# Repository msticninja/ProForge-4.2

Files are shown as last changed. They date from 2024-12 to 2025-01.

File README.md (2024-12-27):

# ProForge 4.2 Tool Changer 3D Printer

P4 2 Enclosure Render

Designed in the UK, the ProForge 4.2 Tool Changer is a state-of-the-art multi-tool 3D printer designed for precision, reliability, and modularity. With its advanced tool-changing mechanism, it enables seamless multi-material and multi-function printing for hobbyists, engineers, and makers.

Available to order [here.](https://www.makertech3d.com/pages/proforge-4)

# Features
	•	Tool-Changing Mechanism: Swap up to 4 tools in a single print.
	•	Large Build Volume: 300mm x 400mm x 400mm.
	•	Multi-Material Compatibility: Support for various filaments like PLA, ABS, PETG, and flexible materials.
	•	Advanced Calibration System: Automated nozzle alignment and offset calibration.
	•	Bed Scanning: A mesh of 2500 points is created in seconds for the perfect first layer.
	•	Klipper Firmware: High-speed and responsive motion control.

# ProForge 4.2 Klipper Firmware Image

The Klipper firmware image is available to download [here](https://mega.nz/file/s3c2yLpL#45p-zCgpL2xGsliyOl72hiXyFS9ZQuSpQ91LdNRgVnc).

# ProForge 4.2 Build Manual

The Official build guides for the ProForge 4.2 3D printer can be found [here](https://makertech-3d.dozuki.com/c/ProForge_4.2)

# Support and Community

If you run into any issues or need assistance with assembly or printing, feel free to ask for help in the official [Discord Server](https://discord.com/invite/FwgXFUw4R4)  or [Facebook Group](https://www.facebook.com/groups/proforge4).

If you’re missing a part or have received a faulty/broken one, please fill out [this form](https://www.makertech3d.com/missingpartform) for a replacement.

Want to get in touch? Drop us an email at info@makertech3d.com

# Safety Notice

Operate the ProForge 4.2 in a well ventilated, open and dry environment.

Be aware of the moving parts, there is a pinching hazard.

Be cautious of the Hotend, it can reach temperatures exceeding 300 degrees Celsius, this is hot enough to cause severe burns. Even after operation, the hotends can still be hot, allow time for them to cool before touching.

Keep children and pets away from the ProForge 4.2 whilst in operation.

Never disconnect any of the wiring whilst powered on.

Be careful of long hair and loose clothing when operating the ProForge 4.2.

Immediately shut down the ProForge 4.2 if an error occurs to prevent damage to the unit or its surroundings.

# Disclaimer

THIS PRODUCT IS A DO-IT-YOURSELF KIT TO BE ASSEMBLED BY THE USER AT THEIR OWN RISK. MAKERTECH 3D LTD DISCLAIMS ALL RESPONSIBILITY, RISK, OR LIABILITY OF ANY DAMAGE OR INJURY TO YOURSELF OR ANY PERSON OR PROPERTY FROM ITS USE.

NEITHER MAKERTECH 3D NOR ITS SUPPLIERS SHALL BE LIABLE TO YOU OR TO ANY THIRD PARTY FOR ANY INDIRECT, INCIDENTAL, CONSEQUENTIAL, SPECIAL, PUNITIVE, OR EXEMPLARY DAMAGES (INCLUDING IN EACH CASE, BUT NOT LIMITED TO, DAMAGES FOR THE INABILITY TO USE OR ACCESS THE PRODUCTS, LOSS OF DATA, LOSS OF BUSINESS, LOSS OF PROFITS, BUSINESS INTERRUPTION OR THE LIKE) ARISING OUT OF THE USE OF OR INABILITY TO USE THE PRODUCTS, EVEN IF MAKERTECH 3D HAS BEEN ADVISED OF THE POSSIBILITY OF SUCH DAMAGES.

MAKERTECH 3D IS NOT RESPONSIBLE FOR ANY PRODUCTS (3D PRINTED PARTS OR OTHER) PRODUCED WITH THE PROFORGE 3 OR ANY OF ITS OTHER PRODUCTS. IN NO EVENT SHALL MAKERTECH 3D BE LIABLE FOR ANY DAMAGE OR INJURY OCCURRED BY USING PRODUCTS PRODUCED BY THE PROFORGE 3 OR ANY OF ITS OTHER PRODUCTS.

NOTWITHSTANDING ANY DAMAGES THAT YOU MIGHT INCUR FOR ANY REASON WHATSOEVER (INCLUDING, WITHOUT LIMITATION, ALL DAMAGES REFERENCED HEREIN AND ALL DIRECT OR GENERAL DAMAGES IN CONTRACT OR ANYTHING ELSE), THE ENTIRE LIABILITY OF MAKERTECH 3D AND ANY OF ITS SUPPLIERS ARISING FROM OR RELATED TO THE USE OF THE PRODUCTS SHALL BE LIMITED TO THE AMOUNT ACTUALLY PAID BY YOU FOR THE PRODUCTS CONCERNED.

THE CUSTOMER IS FULLY AWARE OF THE TERMS OF USE MENTIONED IN THE ASSEMBLY MANUALS PROVIDED WITH THE PRODUCT AND AGREES WITH THESE TERMS OF USE WHEN ACCEPTING THE PRODUCT.

THE CUSTOMER HAS READ THE SAFETY INSTRUCTIONS PROVIDED IN THE MANUALS TO BUILD THE DIY-PRODUCTS OF MAKERTECH 3D. THE CUSTOMER ALSO AGREES IN FOLLOWING THESE SAFETY INSTRUCTIONS.

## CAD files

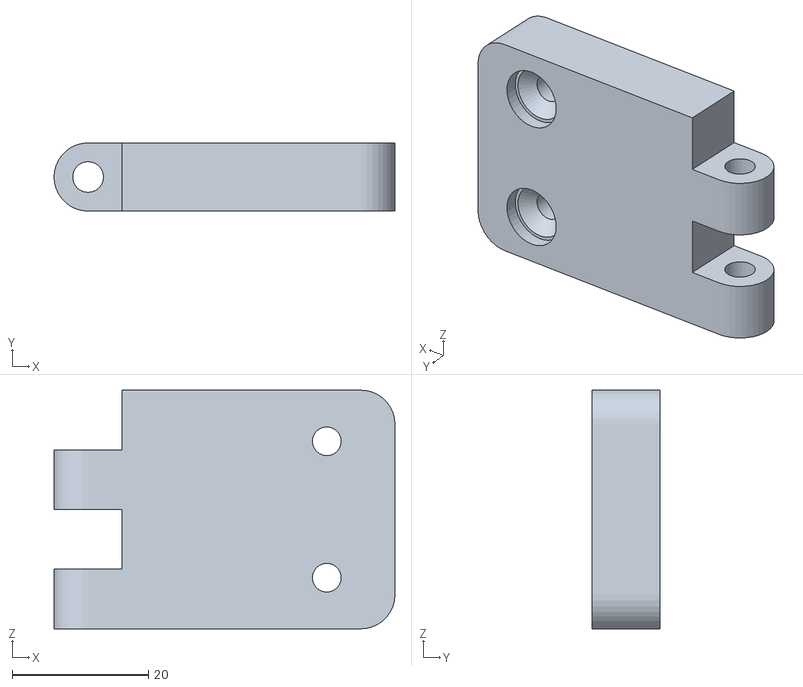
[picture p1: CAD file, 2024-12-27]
3D Printed Parts/P4.2 - Roof Hinge A.STL
50.0 x 10.0 x 35.0

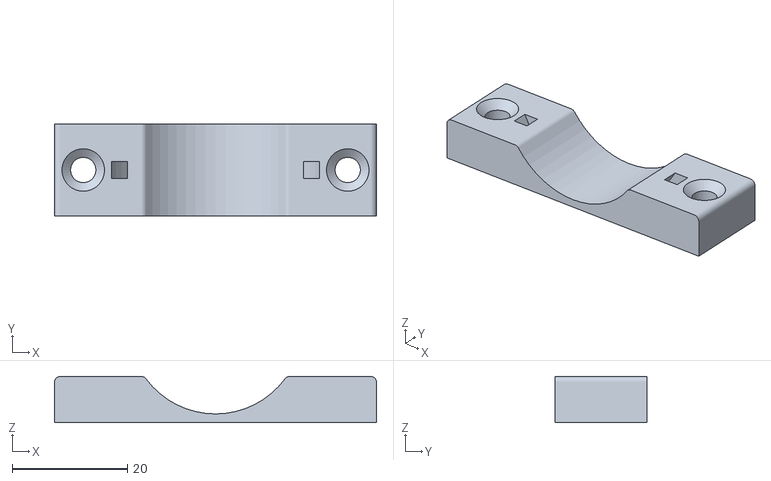
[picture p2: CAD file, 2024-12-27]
3D Printed Parts/P4.2 - CPAP Support Bracket.STL
56.0 x 16.0 x 8.02

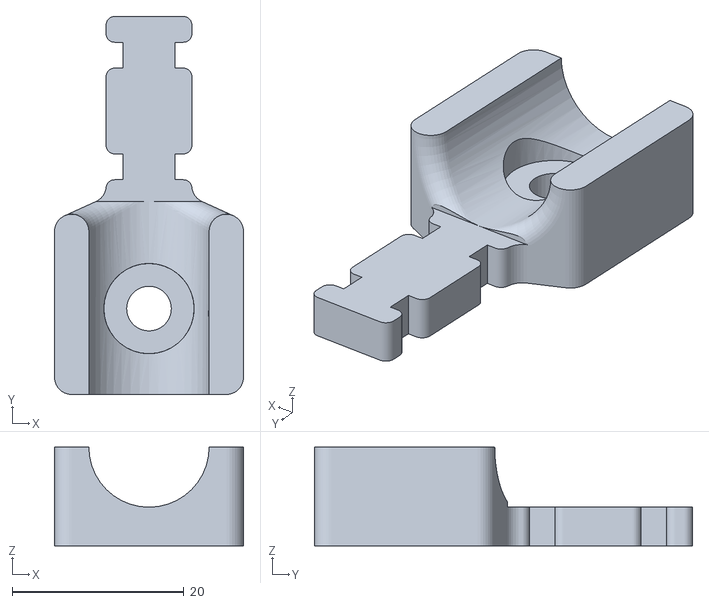
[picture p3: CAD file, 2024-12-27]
3D Printed Parts/P4.2 - Cable Relief.STL
22.0 x 44.0 x 11.5

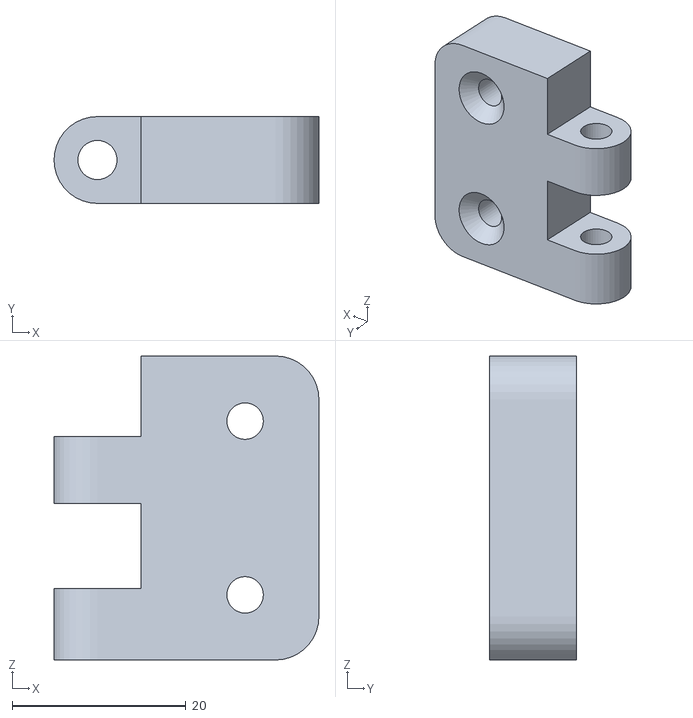
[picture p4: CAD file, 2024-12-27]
3D Printed Parts/P4.2 - Roof Hinge B.STL
30.5 x 10.0 x 35.0

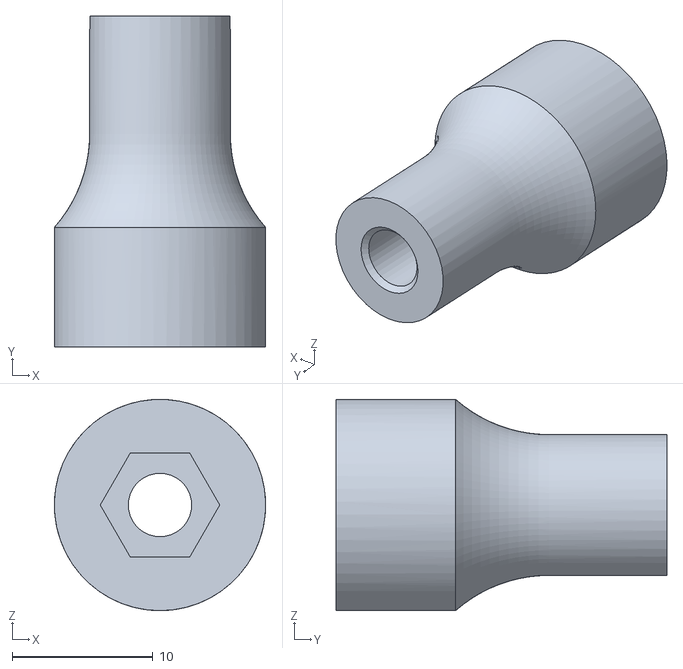
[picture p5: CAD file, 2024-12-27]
3D Printed Parts/P4.2 - Endstop Trigger.STL
15.0 x 23.5 x 15.0

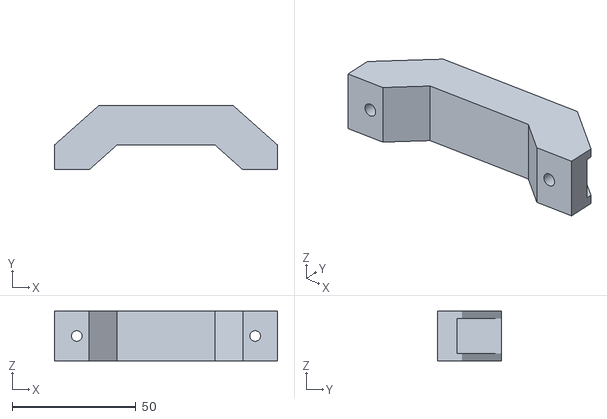
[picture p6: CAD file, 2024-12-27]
3D Printed Parts/P4.2 - Roof Handle.STL
90.0 x 26.0 x 20.0

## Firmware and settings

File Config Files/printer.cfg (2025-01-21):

############################################################################
####################### ProForge 4.2 Printer Config ########################
############################################################################

#config file version v1.0.0
#release date: 28.12.2024


[include mainsail.cfg]
[include macros.cfg]
[include eddy.cfg]
[include calibrate-offsets.cfg]
#[include so3_0.cfg]
#[include so3_1.cfg]
#[include so3_2.cfg]
#[include so3_3.cfg]

[save_variables]
filename: ~/printer_data/config/variables.cfg
#   Required - provide a filename that would be used to save the
#   variables to disk e.g. ~/variables.cfg
[virtual_sdcard]
path: ~/printer_data/gcodes

[force_move]
enable_force_move: True

[mcu]
serial: /dev/serial/by-id/


[printer]
kinematics: corexy
max_velocity: 800
max_accel: 60000
minimum_cruise_ratio: 0.65
square_corner_velocity: 10.0
max_z_velocity: 12
max_z_accel: 100

[gcode_arcs]
resolution: 0.2


# MOTOR-1
[stepper_x]
step_pin: PC13
dir_pin: PC14
enable_pin: !PE6
rotation_distance: 40  # Adjust based on your lead screw or belt system
microsteps: 16
full_steps_per_rotation: 200  # Motor step angle: 1.8° = 200 steps per rotation
#gear_ratio: 1
#step_pulse_duration: 2  # Add if the driver requires a specific pulse width
endstop_pin: PF0
position_min: -100
position_endstop: 400
position_max: 400
homing_speed: 130  # mm/s; adjust for your mechanics
homing_retract_speed: 25  # mm/s
[tmc5160 stepper_x]
cs_pin: PG14
spi_speed: 2000000
spi_software_sclk_pin: PE12
spi_software_mosi_pin: PE14
spi_software_miso_pin: PE13
interpolate: True
run_current: 2.2  # Adjusted for 2.5A motor rating (approximately 85-90% for safety)
hold_current: 1.0  # Reduce for lower heat generation during idle
sense_resistor: 0.05
stealthchop_threshold: 0  # Disabled for better torque and stability on X-axis
# Optional Driver Tuning
driver_TBL: 2  # Adjusted for smooth performance; default is 1
driver_TOFF: 3
driver_PWM_OFS: 30  # Fine-tune if needed for smoother operation
driver_PWM_GRAD: 4


# MOTOR-2
[stepper_y]
step_pin: PE4
dir_pin: !PE5
enable_pin: !PE3
rotation_distance: 40  # Adjust based on your belt/pulley system
microsteps: 16
full_steps_per_rotation: 200  # Motor step angle: 1.8° = 200 steps per rotation
#gear_ratio: 1
#step_pulse_duration: 2  # Add if the driver requires a specific pulse width
endstop_pin: PF2
position_min: 0
position_endstop: 300
position_max: 300
homing_speed: 130  # mm/s; adjust if necessary for your mechanics
homing_retract_speed: 25  # mm/s
[tmc5160 stepper_y]
cs_pin: PG13
spi_speed: 2000000
spi_software_sclk_pin: PE12
spi_software_mosi_pin: PE14
spi_software_miso_pin: PE13
interpolate: True
run_current: 2.2  # Adjusted to ~85-90% of the motor's rated 2.5A for safe operation
hold_current: 1.0  # Reduced for less heat generation during idle
sense_resistor: 0.05
stealthchop_threshold: 0  # Disabled to keep torque consistent for the Y-axis
# Optional Driver Tuning
driver_TBL: 2  # Adjusted for smooth operation; default is 1
driver_TOFF: 3
driver_PWM_OFS: 30  # Fine-tune for smoother motion if necessary
driver_PWM_GRAD: 4


# MOTOR-3
[stepper_z]
step_pin: PE1
dir_pin: PE0
enable_pin: !PE2
microsteps: 16
rotation_distance: 8
endstop_pin: probe:z_virtual_endstop
position_max: 400
position_min: -3.5
[tmc2209 stepper_z]
uart_pin: PG12
run_current: 0.6
sense_resistor: 0.11
stealthchop_threshold: 0
interpolate: True           # Enables interpolation for smoother movement
hold_current: 0.5           # Sets a lower current when idle to reduce heat

# MOTOR-4
[stepper_z1]
step_pin: PB8
dir_pin: PB9
enable_pin: !PB7
microsteps: 16
rotation_distance: 8
[tmc2209 stepper_z1]
uart_pin: PG11
run_current: 0.6
sense_resistor: 0.11
stealthchop_threshold: 0
interpolate: True           # Enables interpolation for smoother movement
hold_current: 0.5           # Sets a lower current when idle to reduce heat

# MOTOR-5
[stepper_z2]
step_pin: PB5
dir_pin: PB4
enable_pin: !PB6
microsteps: 16
rotation_distance: 8
[tmc2209 stepper_z2]
uart_pin: PG10
run_current: 0.6
sense_resistor: 0.11
stealthchop_threshold: 0
interpolate: True           # Enables interpolation for smoother movement
hold_current: 0.5           # Sets a lower current when idle to reduce heat

# MOTOR-6
[stepper_z3]
step_pin: PG15
dir_pin: PB3
enable_pin: !PD5
microsteps: 16
rotation_distance: 8
[tmc2209 stepper_z3]
uart_pin: PG9
run_current: 0.6
sense_resistor: 0.11
stealthchop_threshold: 0
interpolate: True           # Enables interpolation for smoother movement
hold_current: 0.5           # Sets a lower current when idle to reduce heat


[heater_bed]
heater_pin: PF5
sensor_type: Generic 3950
sensor_pin: PB1
control: pid
pid_Kp: 54.3
pid_Ki: 1.12
pid_Kd: 656.1
min_temp: 0
max_temp: 125

[fan]
pin: PA6
kick_start_time: 0.250

[fan_generic static_fan]
pin: PA5
kick_start_time: 0.250

[fan_generic filter_fan]
pin: PA4
kick_start_time: 0.250


[z_tilt]
z_positions:
 -70, -55
 -70, 355
 470, 355
 470, -55
points:
 6, 94
 6, 264
 276, 264
 276, 94
speed: 300
horizontal_move_z: 10
retries: 0
retry_tolerance: 0.2


[servo toolchanger]
pin: PF12
maximum_servo_angle: 180
minimum_pulse_width: 0.0005
maximum_pulse_width: 0.0025


[respond]
default_type: echo

#*# <---------------------- SAVE_CONFIG ---------------------->
#*# DO NOT EDIT THIS BLOCK OR BELOW. The contents are auto-generated.
#*#
#*# [probe_eddy_current btt_eddy]
#*# reg_drive_current = 16
#*# calibrate =
#*# 	0.050000:3198526.526,0.090000:3197905.442,0.130000:3197355.822,
#*# 	0.170000:3196796.942,0.210000:3196248.858,0.250000:3195690.924,
#*# 	0.290000:3195163.935,0.330000:3194648.527,0.370000:3194130.318,
#*# 	0.410000:3193598.152,0.450000:3193125.842,0.490000:3192617.996,
#*# 	0.530000:3192145.235,0.570000:3191650.815,0.610000:3191223.067,
#*# 	0.650000:3190749.001,0.690000:3190300.941,0.730000:3189858.277,
#*# 	0.770000:3189415.544,0.810000:3189010.160,0.850000:3188601.996,
#*# 	0.890000:3188152.519,0.930000:3187745.005,0.970000:3187352.679,
#*# 	1.010000:3186962.029,1.050000:3186568.304,1.090000:3186202.254,
#*# 	1.130000:3185843.248,1.170000:3185474.262,1.210000:3185101.141,
#*# 	1.250000:3184758.967,1.290000:3184414.998,1.330000:3184079.071,
#*# 	1.370000:3183733.095,1.410000:3183394.897,1.450000:3183064.751,
#*# 	1.490000:3182758.510,1.530000:3182416.550,1.570000:3182118.960,
#*# 	1.610000:3181809.350,1.650000:3181525.871,1.690000:3181225.635,
#*# 	1.730000:3180943.036,1.770000:3180639.190,1.810000:3180369.148,
#*# 	1.850000:3180097.822,1.890000:3179814.901,1.930000:3179543.299,
#*# 	1.970000:3179295.570,2.010000:3179023.609,2.050000:3178771.511,
#*# 	2.090000:3178528.524,2.130000:3178280.827,2.170000:3178029.194,
#*# 	2.210000:3177802.752,2.250000:3177565.417,2.290000:3177329.956,
#*# 	2.330000:3177102.195,2.370000:3176867.973,2.410000:3176646.146,
#*# 	2.450000:3176438.630,2.490000:3176246.125,2.530000:3176011.643,
#*# 	2.570000:3175810.439,2.610000:3175615.649,2.650000:3175408.897,
#*# 	2.690000:3175199.444,2.730000:3175007.969,2.770000:3174813.781,
#*# 	2.810000:3174624.190,2.850000:3174446.593,2.890000:3174254.222,
#*# 	2.930000:3174080.700,2.970000:3173891.042,3.010000:3173714.917,
#*# 	3.050000:3173585.127,3.090000:3173373.525,3.130000:3173233.271,
#*# 	3.170000:3173043.821,3.210000:3172889.763,3.250000:3172714.791,
#*# 	3.290000:3172560.274,3.330000:3172415.624,3.370000:3172257.802,
#*# 	3.410000:3172108.241,3.450000:3171966.044,3.490000:3171808.505,
#*# 	3.530000:3171653.033,3.570000:3171520.606,3.610000:3171386.071,
#*# 	3.650000:3171272.530,3.690000:3171123.549,3.730000:3170990.889,
#*# 	3.770000:3170851.432,3.810000:3170717.121,3.850000:3170590.115,
#*# 	3.890000:3170471.961,3.930000:3170349.249,3.970000:3170226.433,
#*# 	4.010000:3170085.205,4.050000:3169953.543
#*#
#*# [temperature_probe btt_eddy]
#*# calibration_temp = 37.568756
#*# drift_calibration =
#*# 	3216794.178052, -756.187724, 5.682431
#*# 	3205129.911902, -549.350934, 3.959075
#*# 	3195562.582891, -371.831312, 2.403638
#*# 	3188713.088080, -269.956055, 1.599835
#*# 	3182989.982503, -179.392905, 0.844887
#*# 	3178399.472940, -108.858963, 0.244867
#*# 	3174720.091139, -55.674026, -0.209307
#*# 	3171646.501918, -11.020097, -0.591506
#*# 	3168980.472345, 28.850101, -0.921956
#*# drift_calibration_min_temp = 32.72813346800706
#*#
#*# [input_shaper]
#*# shaper_type_x = ei
#*# shaper_freq_x = 67.6
#*# shaper_type_y = ei
#*# shaper_freq_y = 66.4

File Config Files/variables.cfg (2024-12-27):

############################################################################
##################### ProForge 4.2 Variables Config ########################
############################################################################


#config file version v1.0.0
#release date: 28.12.2024


[Variables]

#Active Print Heads:
active_tools = 0			#Set to number of print heads installed.


# Tool Head SELECT Positions:

# Tool Head 0:
zero_select_x = 0
zero_select_y = 0

# Tool Head 1:
one_select_x = 0
one_select_y = 0

# Tool Head 2:
two_select_x = 0
two_select_y = 0

# Tool Head 3:
three_select_x = 0
three_select_y = 0


# Tool Head DOCKING Positions:

# Tool Head 0:
zero_dock_x = 0
zero_dock_y = 0

# Tool Head 1:
one_dock_x = 0
one_dock_y = 0

# Tool Head 2:
two_dock_x = 0
two_dock_y = 0

# Tool Head 3:
three_dock_x = 0
three_dock_y = 0



# Tool Head X/Y Offsets:

# Tool Head 0: 
# (0,0,0) - reference position


# Tool Head 1 Offset:
one_x_offset = 0
one_y_offset = 0
one_z_offset = 0

# Tool Head 2 Offset:
two_x_offset = 0
two_y_offset = 0
two_z_offset = 0

# Tool Head 3 Offset:
three_x_offset = 0
three_y_offset = 0
three_z_offset = 0

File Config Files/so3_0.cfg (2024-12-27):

############################################################################
##################### SmartOrbiter v3 - Print Head 0 #######################
############################################################################

#config file version v1.0.0
#release date: 18.12.2024

[mcu so3_0]
serial: /dev/serial/by-id/



#################################################################################################################
################################ CHANGE HERE MACRO CONFIGURABLES ################################################
#################################################################################################################

[gcode_macro _SENSOR_VARIABLES_0]         # change here macro configurables, enable disable functions!*************************
variable_filament_load_temp     :220    # temperature to heat up hotend for filament loading, default is 235
variable_filament_unload_temp   :185    # temperature to heat up hotend for filament un-loading, default is 185
variable_filament_load_min_temp :190    # minimum hotend set temperature allowed in filament load macro, default is 190
variable_nozzle_purge_length    :100    # filament extrude amount during load sequenc, hotend purge from old filament, default is 100
variable_nozzle_purge_speed     :300    # filament extrude speed in mm/min adjust this value lower if flow is too high and extruder skips during loading, default is 300
variable_disable_autoload       :False  # disable filament autoload feature by setting this variable True
variable_disable_runnout        :False  # disable runnout by setting this variable True
variable_disable_autounload     :False  # disable auto unload filament by setting this variable to True
variable_enable_beep            :False   # uses M300 sound feature, set it True to enable
variable_SENSOR_RGB_LED         :False  # enable and configure RGB LED pin and type for filament status indication
variable_park_position_x        :100    # edit your X parking position here for pause macro trigerred by runnout
variable_park_position_y        :10     # edit your Y parking position here for pause macro trigerred by runnout
variable_park_lift_z            :10     # edit your Z lift amount for parking position here, default is 10
variable_park_retraction        :1      # edit your retraction amount for parking, default is 1
gcode:


##################################################################
########################## EXTRUDER ##############################
##################################################################
[extruder]
step_pin: so3_0:PB7
dir_pin: so3_0:PB6
enable_pin: !so3_0:PB4
microsteps: 32
full_steps_per_rotation: 200
#rotation_distance = <full_steps_per_rotation> * <microsteps> / <steps_per_mm>
rotation_distance: 4.69
nozzle_diameter: 0.400
filament_diameter: 1.750
max_extrude_only_distance: 2500
max_extrude_only_velocity: 120
max_extrude_only_accel: 3000
heater_pin: so3_0:PA0
sensor_type: ATC Semitec 104NT-4-R025H42G  
sensor_pin: so3_0:PA2
pullup_resistor: 4700
min_temp: 0
max_temp: 300
pressure_advance: 0.03
pressure_advance_smooth_time: 0.02
min_extrude_temp: 165
smooth_time: 0.5
max_extrude_cross_section:10
max_power: 0.995
pwm_cycle_time: 0.01
control = pid
#Default SO3 PID Values:
pid_Kp=24.859 
pid_Ki=2.072 
pid_Kd=74.578
#REVO SO3 PID Values:
#pid_Kp=23.445
#pid_Ki=1.839
#pid_Kd=74.733
[tmc2209 extruder] 
uart_pin: so3_0:PB5
#uart_address: 3 # comment out this line in case UART address definition is not required
interpolate: true
run_current: 0.80
sense_resistor: 0.11
stealthchop_threshold: 0

[heater_fan Hotend0_Fan]
pin: !so3_0:PA8
tachometer_pin: so3_0:PA3
tachometer_ppr: 2
tachometer_poll_interval: 0.0005
heater: extruder
cycle_time: 0.0001 #10KHz PWM frecvency
#cycle_time: 0.01 #100Hz PWM frecvency
heater_temp: 75
fan_speed: 0.65
hardware_pwm: false
shutdown_speed: 0.0
max_power: 1.0


#################################################################################################################################
####################################### DO NOT CHANGE ANYTHING BELOW THIS LINE!!! ###############################################
#################################################################################################################################
####################################### UNLESS YOU KNOW WHAT YOU ARE DOING OR YOU ARE BORED AND NEED TO DO SOMETHING OR YOU ARE ALONE AND NEED SOMETHING TO MESS UP YOUR LIFE OR YOU CAN DO IT BETTER THAN ME OR YOU ARE A REAL SMARTASS OR JUST BECAUSE YOU CAN OR YOU RUN OUT OF BEAR OR HAS NOTHING BETTER TO DO OR ANY UNREASONABLE REASON
#################################################################################################################################

[respond]
default_type: echo

[force_move]
enable_force_move: True

#################################################################################################################################
########################################### so3_0 Features Configuration ##########################################################
#################################################################################################################################

[neopixel SO3RGB_0]
pin: so3_0:PB8
chain_count: 1
color_order: GRB
initial_RED: 0.5
initial_GREEN: 0.5
initial_BLUE: 0.5

[thermistor so3_0Thermistor]
temperature1: 25
resistance1: 100000
beta: 3950

[temperature_sensor so3_0]
sensor_type: so3_0Thermistor
sensor_pin: so3_0:PB1
pullup_resistor: 4700
min_temp: 0
max_temp: 85

[output_pin HOT_LED]
pin: so3_0:PA9
value: 1
shutdown_value: 0

[lis2dw]
cs_pin: so3_0:PA4
spi_bus: spi1
axes_map: y, z, x

[resonance_tester]
accel_chip: lis2dw
probe_points: 150,150,30  # edit XYZ head position for testing
min_freq: 10
max_freq: 200

#################################################################################################################################
############################################## Runout and autoload macros #######################################################
#################################################################################################################################

#################################################################################################################################
####################################### DO NOT CHANGE ANYTHING BELOW THIS LINE!!! ###############################################
#################################################################################################################################
####################################### UNLESS YOU KNOW WHAT YOU ARE DOING OR YOU ARE BORED AND NEED TO DO SOMETHING OR YOU ARE ALONE AND NEED SOMETHING TO MESS UP YOUR LIFE OR YOU CAN DO IT BETTER THAN ME OR YOU ARE A REAL SMARTASS OR JUST BECAUSE YOU CAN OR YOU RUN OUT OF BEAR OR HAS NOTHING BETTER TO DO OR ANY UNREASONABLE REASON
#################################################################################################################################


#*****************************initial RGB LED set at printer start****************************************************************
[delayed_gcode startup_RGB_SET_0]
initial_duration: 2
gcode:    
  {% if printer["filament_switch_sensor SO3Sensor_0"].filament_detected==true %}
      SET_LED LED=SO3RGB_0 RED=0.0 GREEN=1.0 BLUE=0.0
  {% else %}
      SET_LED LED=SO3RGB_0 RED=1.0 GREEN=0.0 BLUE=0.0
  {% endif %}   


#***********************************filament swicth definition***********************************************************

[filament_switch_sensor SO3Sensor_0]
switch_pin: so3_0:PA13
pause_on_runout: False # do not change to true, printer is paused in the next sections
runout_gcode: UPDATE_DELAYED_GCODE ID=runnout_filter_0 DURATION=0.5 # duration defines the filter time for runnout detection
insert_gcode: _filament_load_init_0
event_delay: 1.0
pause_delay: 0.1


#////////////////////////////////////////Filament Unload macros/////////////////////////////////////////////////

[gcode_button _filament_unload_0]
pin: !so3_0:PA10
release_gcode:  # filament unload procedure   
  SET_LED LED=SO3RGB_0 RED=0.0 GREEN=0.5 BLUE=0.5
  _filament_unload_init_0
press_gcode: # do not add any macro call here

[delayed_gcode runnout_filter_0]
gcode: #checking if filament runout is still present after defined delay time, default 0.5s
  {% if printer["filament_switch_sensor SO3Sensor_0"].filament_detected==false %}
      _runnout_init_0
  {% else %}
      M118 Runnout sensor_0 intermitent contact detected!
  {% endif %}
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

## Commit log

2024-12-27 3D Printed Parts
    [P4.2 - CPAP Support Bracket.STL, P4.2 - Cable Relief.STL, P4.2 - Endstop Trigger.STL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]
2024-12-27 Config files
    [calibrate-offsets.cfg, eddy.cfg, macros.cfg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]
